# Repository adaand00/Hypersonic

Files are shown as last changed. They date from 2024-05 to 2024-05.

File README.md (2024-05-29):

# Hypersonic
Platform for audio development with ESP32-S3, Work in progress.

Design goals: 
Modularity. Flexibility. High Fidelity. 

Based on previous project: [Supersonic Quantumbox](https://github.com/GustavAbrahamsson/Supersonic-Quantumbox)

## Development progress:

### Hardware
- [x] ESP32-s3 + CODEC module ([`/Hypersonic_pcb`](./Hypersonic_pcb/))
- [x] Pedal with screen, potentiometers, and connetors. ([`/Hypersonic_pedal_pcb`](./Hypersonic_pedal_pcb/))
- [x] Assembled
- [ ] Fully tested

### Software
- [x] Peripheral drivers
- [ ] FreeRTOS system
- [ ] User interface

### Effects

- [x] Saturation (Overdrive/Fuzz)
- [x] VU meter
- [ ] Linear filters
- [ ] Compression
- [ ] Rotary speaker
- [ ] Wah-wah
- [ ] Echo/Reverb

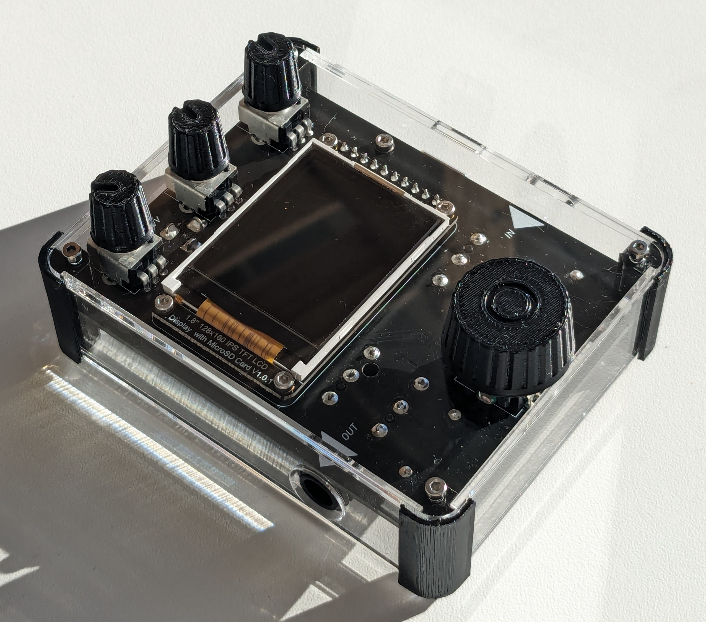
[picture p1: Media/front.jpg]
Pedal


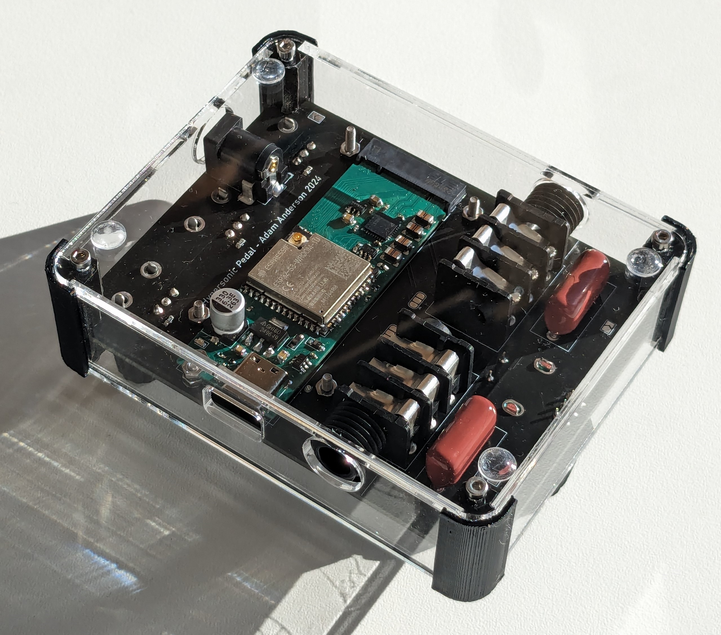
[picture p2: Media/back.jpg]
back


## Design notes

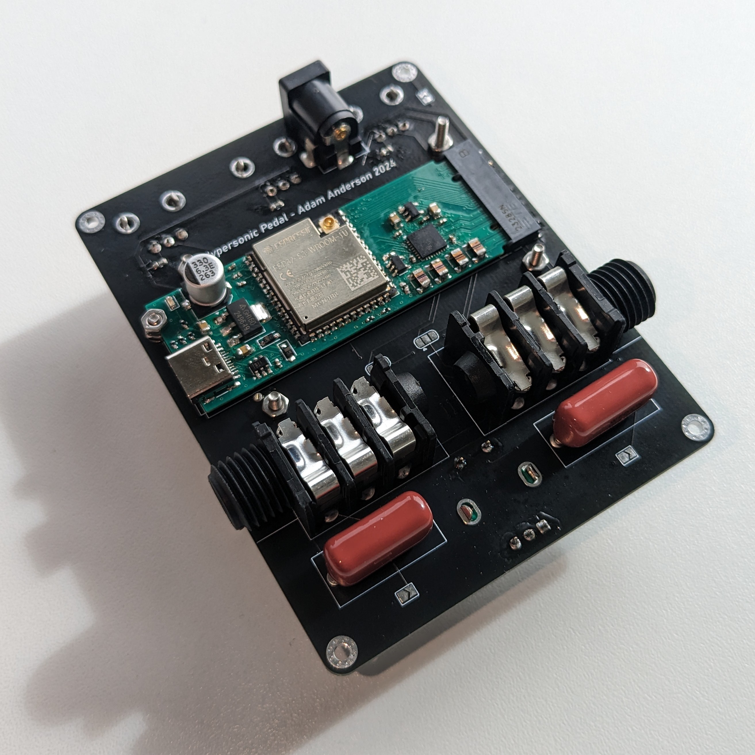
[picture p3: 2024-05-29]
Media/back_open.jpg

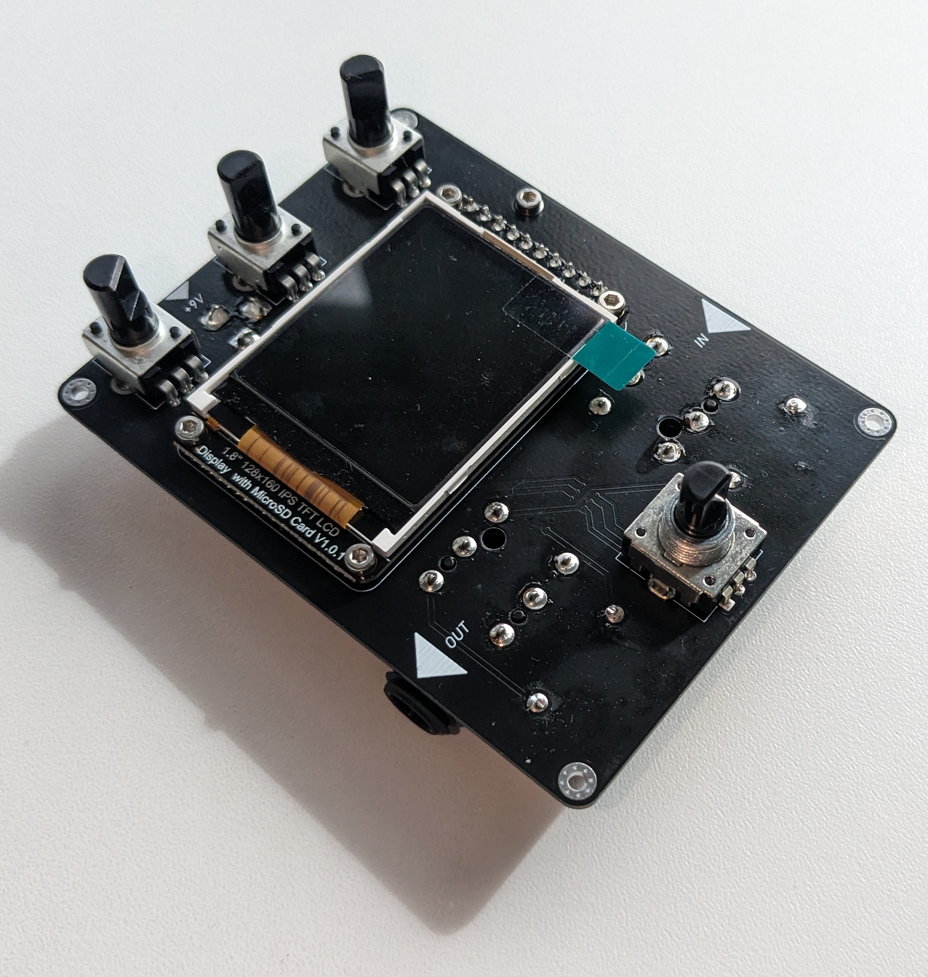
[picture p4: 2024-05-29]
Media/front_open.jpg

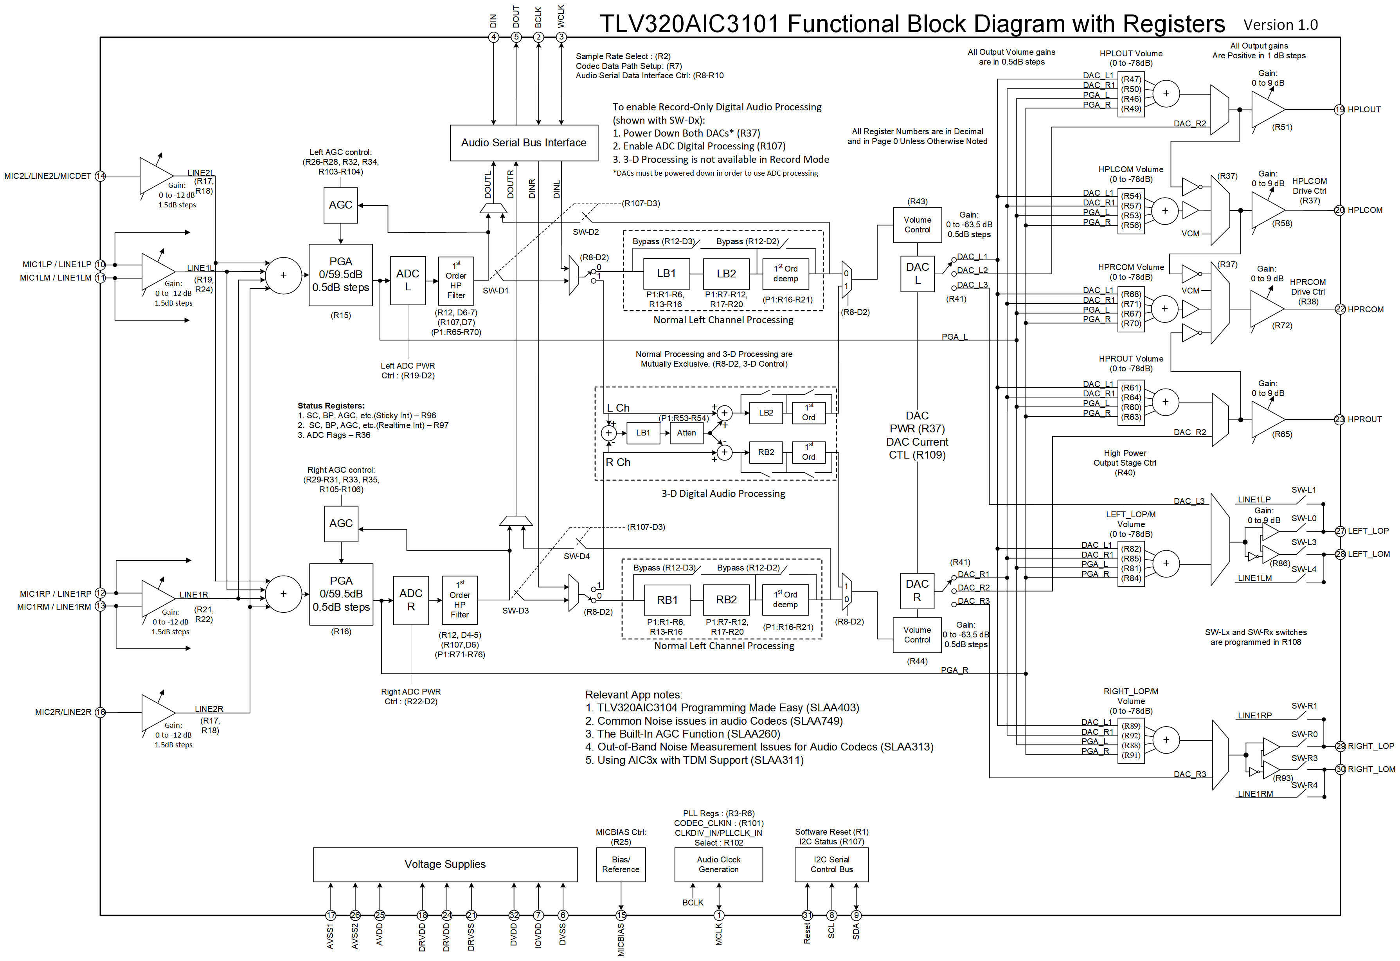
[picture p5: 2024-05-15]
Hypersonic_code/6406.TLV320AIC3101_Functional_block_Diagram_With_Registers.png

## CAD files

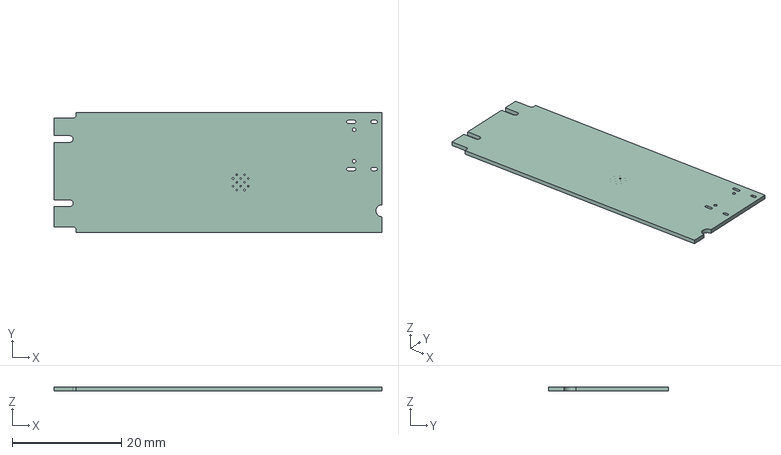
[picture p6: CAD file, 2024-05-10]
Hypersonic_pcb/Hypersonic_pcb.step
60.0 x 22.0 x 0.8 mm

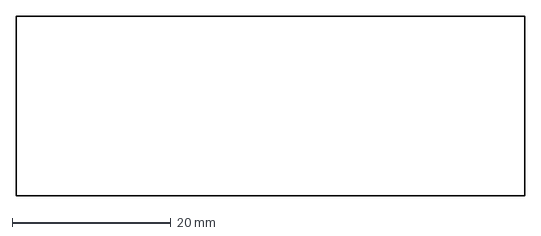
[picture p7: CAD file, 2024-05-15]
Hypersonic_pedal_pcb/case/fron_panel.dxf
64.0 x 22.6 mm

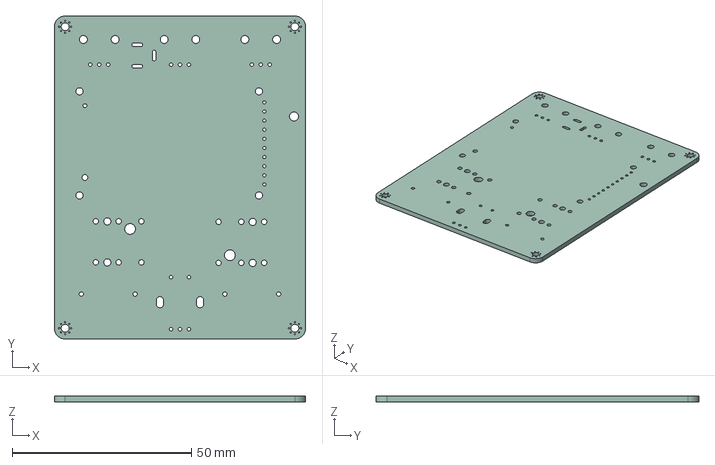
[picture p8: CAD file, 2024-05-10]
Hypersonic_pedal_pcb/Hypersonic_pedal_pcb.step
70.0 x 90.0 x 1.60 mm

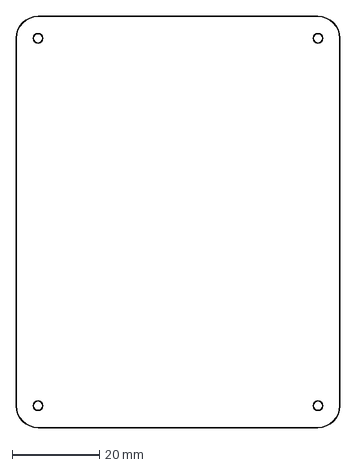
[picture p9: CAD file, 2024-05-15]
Hypersonic_pedal_pcb/case/bottom_panel.dxf
74.0 x 94.0 mm

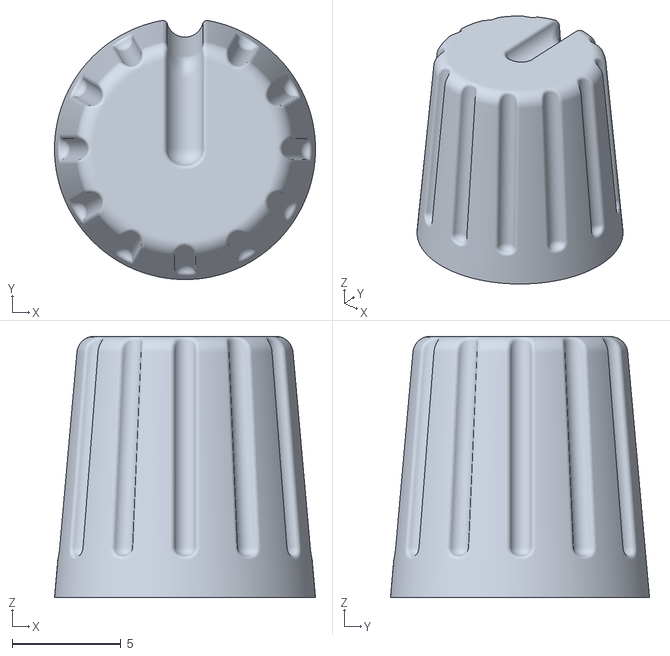
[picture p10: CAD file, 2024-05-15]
Hypersonic_pedal_pcb/case/knob_pot.stl
12.0 x 11.9 x 12.0

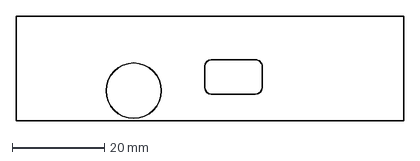
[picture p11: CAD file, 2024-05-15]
Hypersonic_pedal_pcb/case/right_panel.dxf
84.0 x 22.6 mm

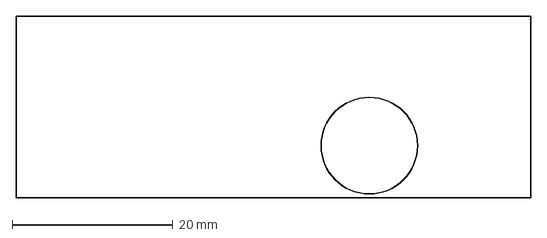
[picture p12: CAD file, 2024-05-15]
Hypersonic_pedal_pcb/case/back_panel.dxf
64.0 x 22.6 mm

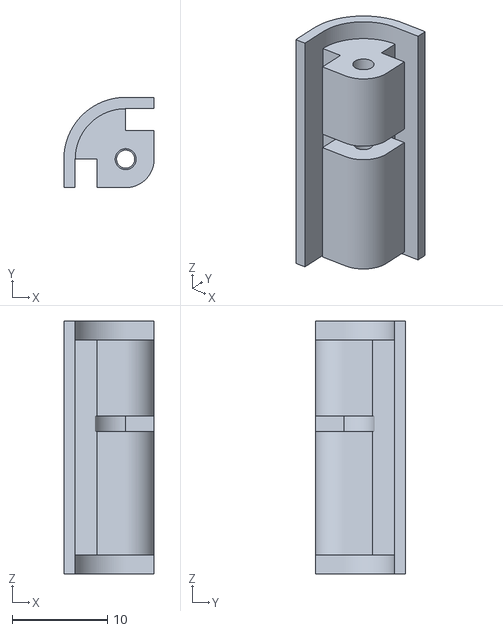
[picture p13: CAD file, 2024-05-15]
Hypersonic_pedal_pcb/case/edge.stl
9.50 x 9.50 x 26.6

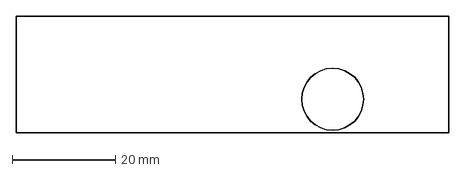
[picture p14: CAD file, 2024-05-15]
Hypersonic_pedal_pcb/case/left_panel.dxf
84.0 x 22.6 mm

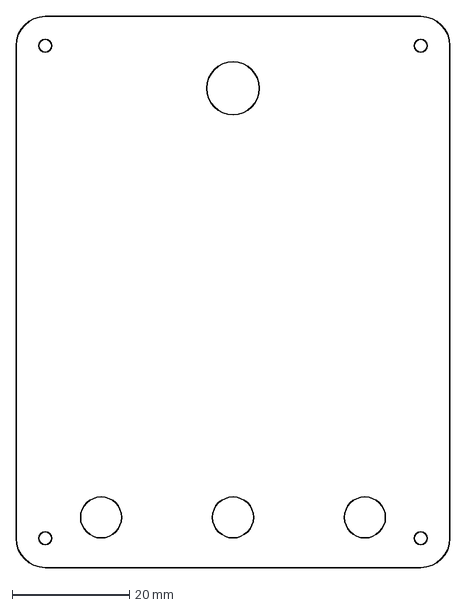
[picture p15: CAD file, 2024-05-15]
Hypersonic_pedal_pcb/case/top_panel.dxf
74.0 x 94.0 mm

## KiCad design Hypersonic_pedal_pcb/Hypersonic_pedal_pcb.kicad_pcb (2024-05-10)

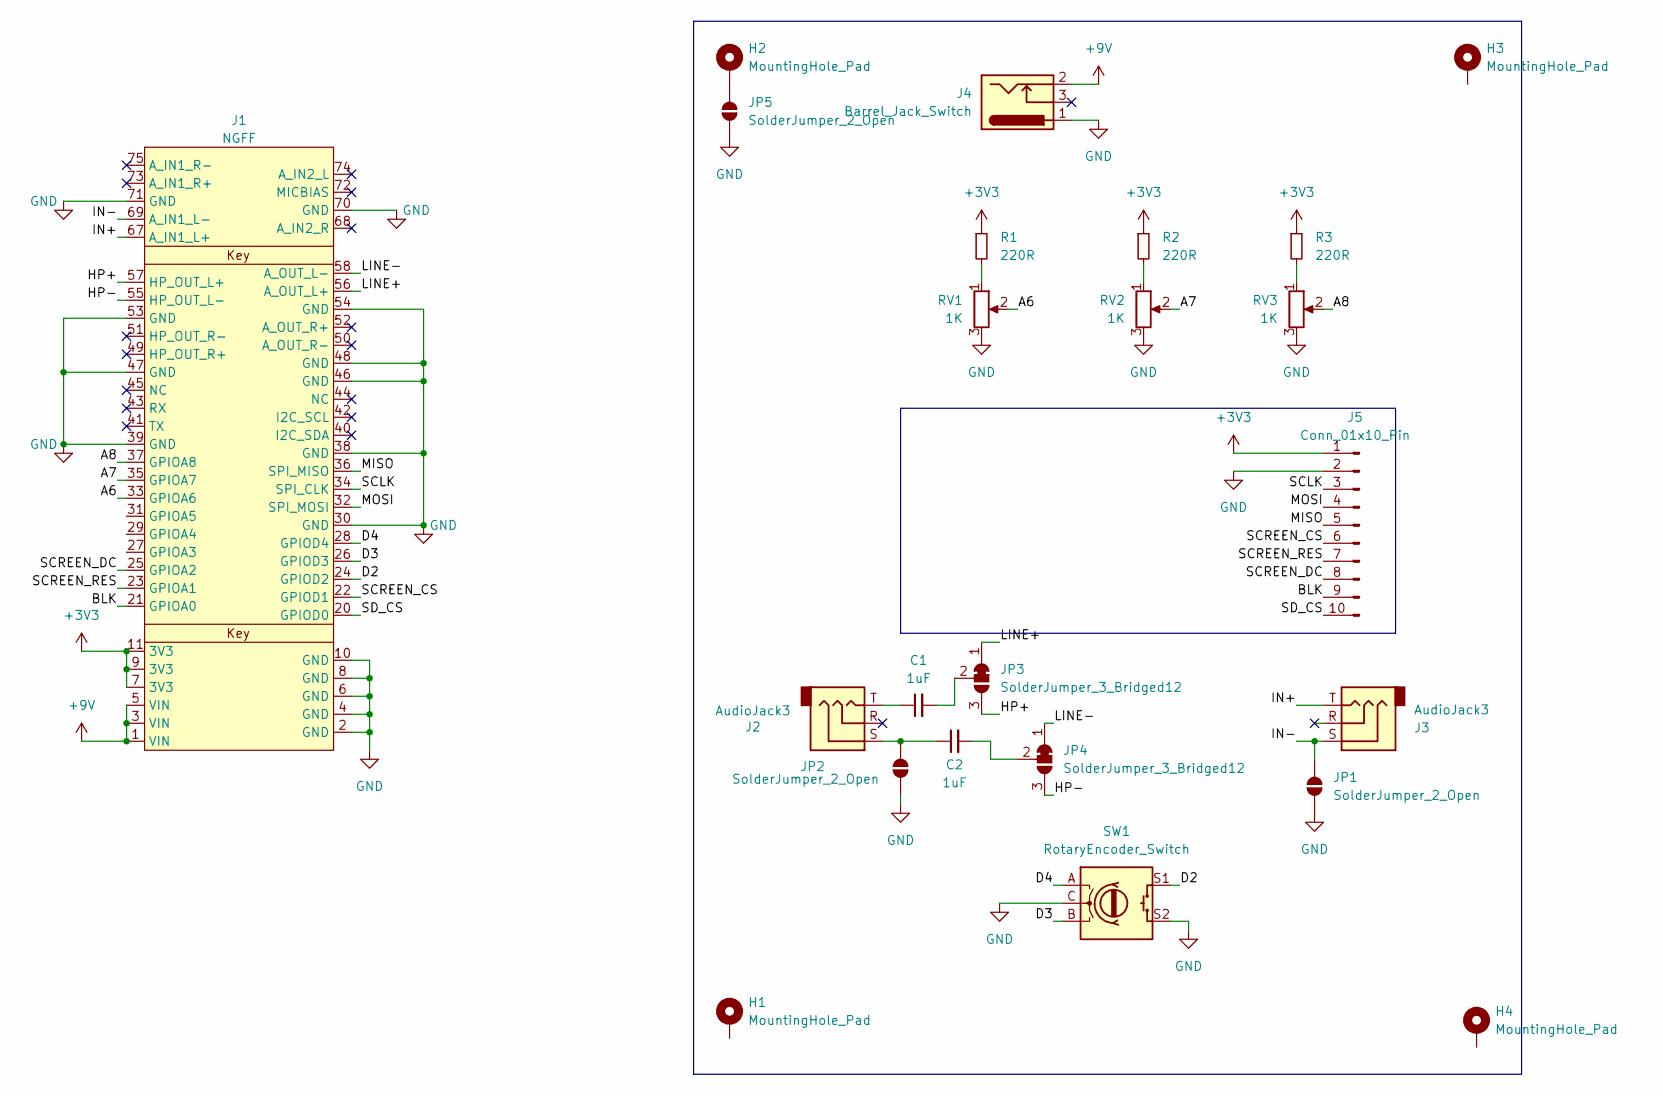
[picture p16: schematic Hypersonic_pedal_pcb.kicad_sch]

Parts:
C1, C2: 1uF; C_Rect_L18.0mm_W8.0mm_P15.00mm_FKS3_FKP3
H1, H2, H3, H4: MountingHole_Pad; MountingHole_2.2mm_M2_Pad_Via
J1: NGFF; TE_2199119-1
J2, J3: AudioJack3; Jack_6.35mm_Neutrik_NRJ6HF_Horizontal
J4: Barrel_Jack_Switch; BarrelJack_Horizontal
J5: Conn_01x10_Pin; DFROBOT_TFT_1_8
JP1, JP2, JP5: SolderJumper_2_Open; SolderJumper-2_P1.3mm_Open_TrianglePad1.0x1.5mm
JP3, JP4: SolderJumper_3_Bridged12; SolderJumper-3_P1.3mm_Bridged12_RoundedPad1.0x1.5mm
R1, R2, R3: 220R; R_0603_1608Metric
RV1, RV2, RV3: 1K; Potentiometer_Bourns_PTV09A-1_Single_Vertical
SW1: RotaryEncoder_Switch; RotaryEncoder_Bourns_Vertical_PEC12R-3x17F-Sxxxx

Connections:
+3V3: J1.7 (3V3), J1.9 (3V3), J1.11 (3V3), J5.1, R1.1, R2.1, R3.1
+9V: J1.1 (VIN), J1.3 (VIN), J1.5 (VIN), J4.2
/A6: J1.33 (GPIOA6), RV1.2
/A7: J1.35 (GPIOA7), RV2.2
/A8: J1.37 (GPIOA8), RV3.2
/BLK: J1.21 (GPIOA0), J5.9
/D2: J1.24 (GPIOD2), SW1.S1
/D3: J1.26 (GPIOD3), SW1.B
/D4: J1.28 (GPIOD4), SW1.A
/HP+: J1.57 (HP_OUT_L+), JP3.3 (B)
/HP-: J1.55 (HP_OUT_L-), JP4.3 (B)
/IN+: J1.67 (A_IN1_L+), J3.T
/IN-: J1.69 (A_IN1_L-), J3.S, JP1.2 (B)
/LINE+: J1.56 (A_OUT_L+), JP3.1 (A)
/LINE-: J1.58 (A_OUT_L-), JP4.1 (A)
/MISO: J1.36 (SPI_MISO), J5.5
/MOSI: J1.32 (SPI_MOSI), J5.4
/SCLK: J1.34 (SPI_CLK), J5.3
/SCREEN_CS: J1.22 (GPIOD1), J5.6
/SCREEN_DC: J1.25 (GPIOA2), J5.8
/SCREEN_RES: J1.23 (GPIOA1), J5.7
/SD_CS: J1.20 (GPIOD0), J5.10
GND: J1.2 (GND), J1.4 (GND), J1.6 (GND), J1.8 (GND), J1.10 (GND), J1.30 (GND), J1.38 (GND), J1.39 (GND), J1.46 (GND), J1.47 (GND), J1.48 (GND), J1.53 (GND), J1.54 (GND), J1.70 (GND), J1.71 (GND), J4.1, J5.2, JP1.1 (A), JP2.1 (A), JP5.1 (A), RV1.3, RV2.3, RV3.3, SW1.C, SW1.S2
unnamed: C1.1, J2.T
unnamed: C2.1, J2.S, JP2.2 (B)
unnamed: C1.2, JP3.2 (C)
unnamed: C2.2, JP4.2 (C)
unnamed: H2.1, JP5.2 (B)
unnamed: R1.2, RV1.1
unnamed: R2.2, RV2.1
unnamed: R3.2, RV3.1

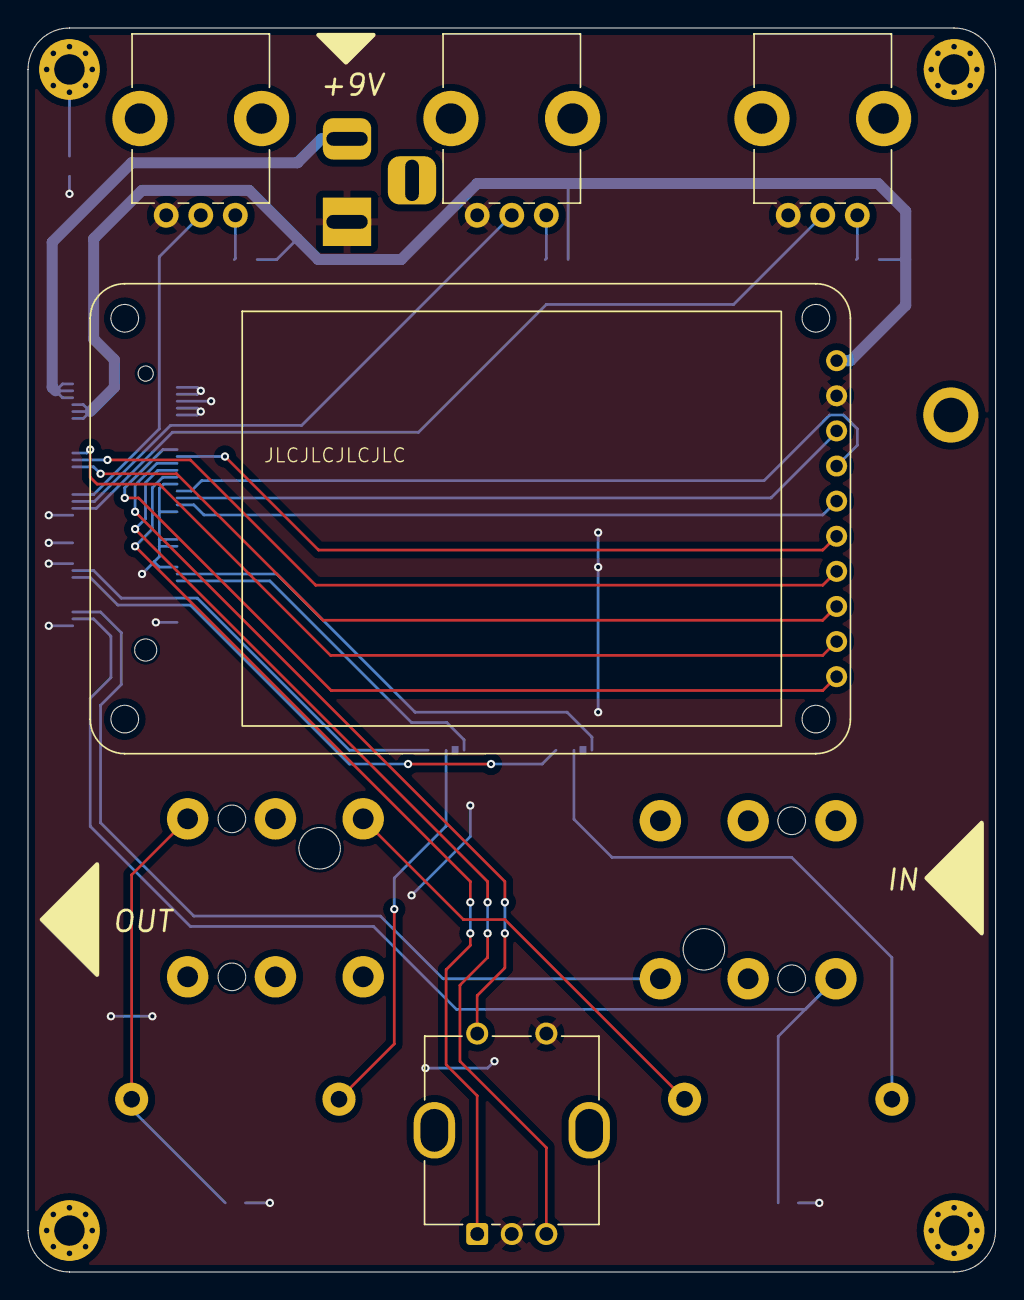
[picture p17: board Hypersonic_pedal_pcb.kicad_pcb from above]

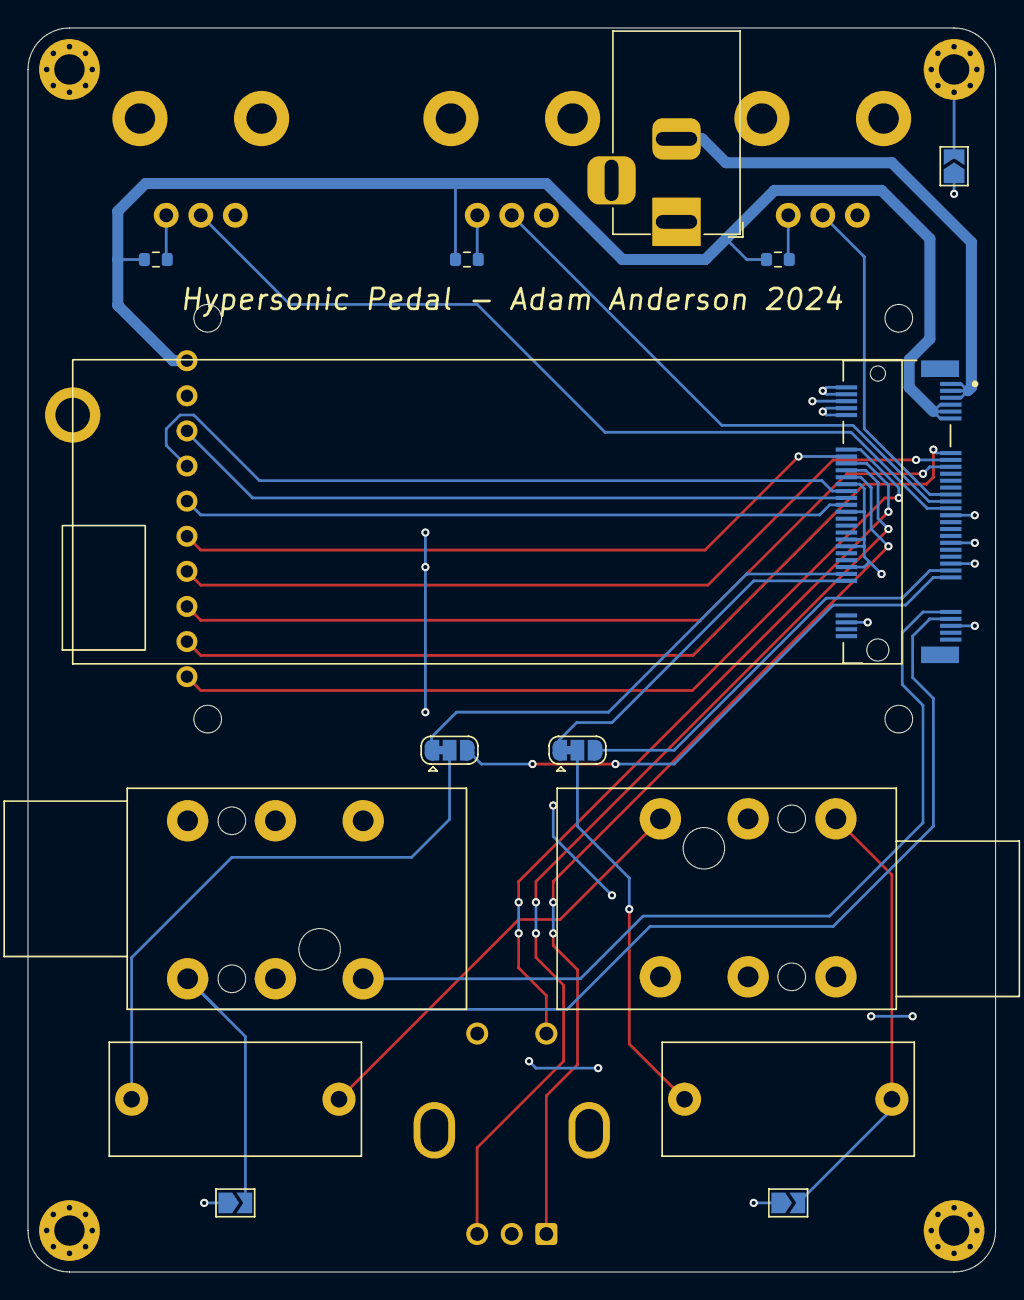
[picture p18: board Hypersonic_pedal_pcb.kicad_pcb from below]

Board: 2 copper layers, 70.0 x 90.0 mm, 23 parts (14 on the bottom side), 31 nets.

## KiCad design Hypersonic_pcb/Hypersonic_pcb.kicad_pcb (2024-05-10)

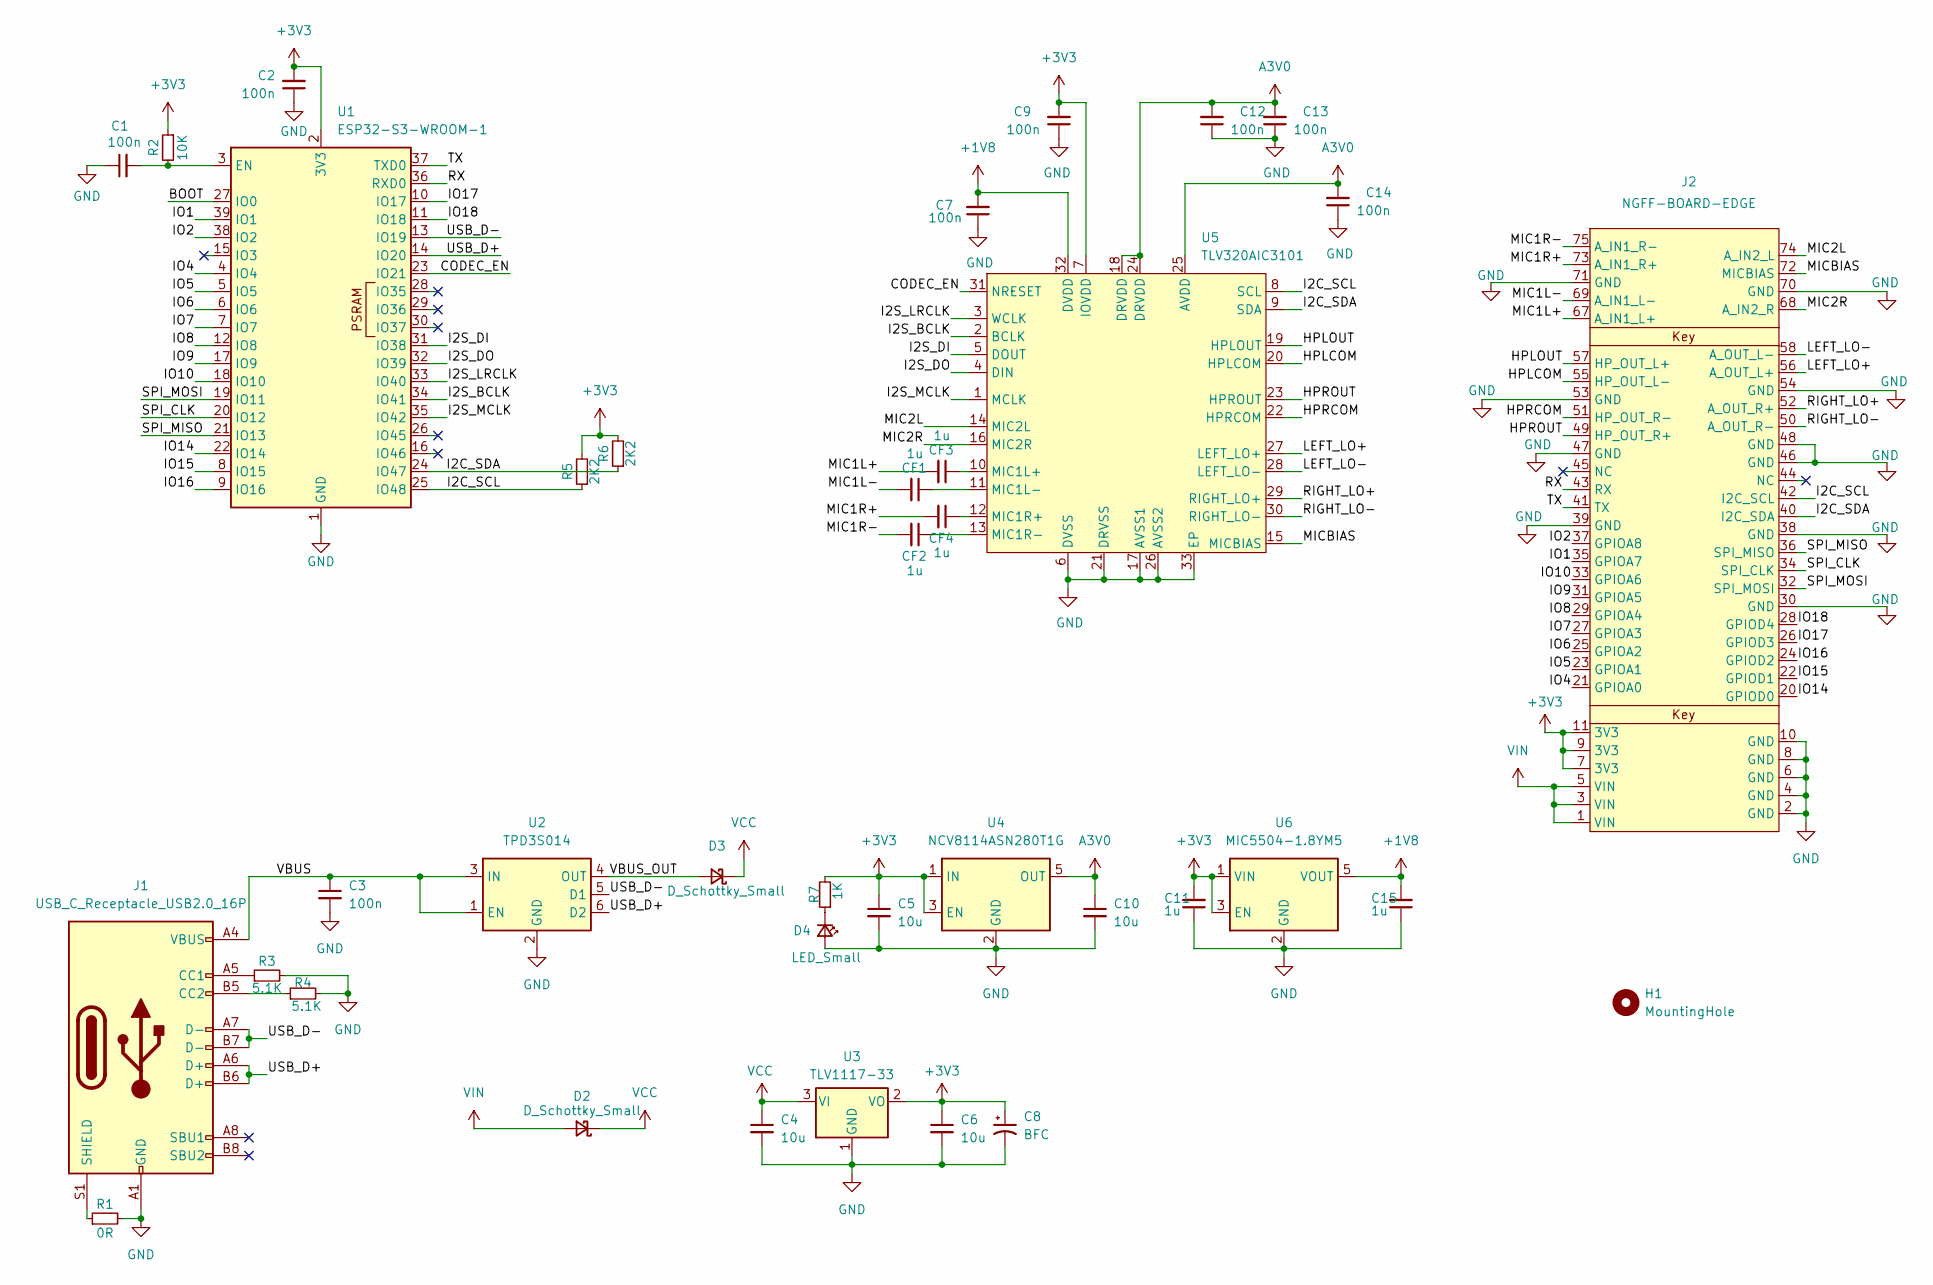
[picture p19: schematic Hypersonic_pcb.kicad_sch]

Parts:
C1, C2, C3, C7, C9, C12, C13, C14: 100n; C_0402_1005Metric
C4, C5, C6, C10: 10u; C_0805_2012Metric
C8: BFC; C_Elec_6.3x5.8
C11, C15: 1u; C_0603_1608Metric
CF1, CF2, CF3, CF4: 1u; C_1210_3225Metric
D2, D3: D_Schottky_Small; D_SOD-323_HandSoldering
D4: LED_Small; LED_0603_1608Metric
H1: MountingHole; MountingHole_2.2mm_M2
J1: USB_C_Receptacle_USB2.0_16P; USB_C_Receptacle_HRO_TYPE-C-31-M-12
J2: NGFF-BOARD-EDGE; NGFF_B+M
R1: 0R; R_0402_1005Metric
R2: 10K; R_0402_1005Metric
R3, R4: 5.1K; R_0402_1005Metric
R5, R6: 2K2; R_0402_1005Metric
R7: 1K; R_0402_1005Metric
U1: ESP32-S3-WROOM-1; ESP32-S3-WROOM-1U
U2: TPD3S014; SOT-23-6
U3: TLV1117-33; SOT-223-3_TabPin2
U4: NCV8114ASN280T1G; TSOT-23-5
U5: TLV320AIC3101; QFN-32-1EP_5x5mm_P0.5mm_EP3.45x3.45mm
U6: MIC5504-1.8YM5; SOT-23-5

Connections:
+1V8: C7.2, C15.2, U5.32 (DVDD), U6.5 (VOUT)
+3V3: C2.2, C5.1, C6.1, C8.1, C9.2, C11.2, J2.7 (3V3), J2.9 (3V3), J2.11 (3V3), R2.1, R5.2, R6.2, R7.2, U1.2 (3V3), U3.2 (VO), U4.1 (IN), U4.3 (EN), U5.7 (IOVDD), U6.1 (VIN), U6.3 (EN)
/BOOT: U1.27 (IO0)
/CODEC_EN: U1.23 (IO21), U5.31 (NRESET)
/HPLCOM: J2.55 (HP_OUT_L-), U5.20 (HPLCOM)
/HPLOUT: J2.57 (HP_OUT_L+), U5.19 (HPLOUT)
/HPRCOM: J2.51 (HP_OUT_R-), U5.22 (HPRCOM)
/HPROUT: J2.49 (HP_OUT_R+), U5.23 (HPROUT)
/I2C_SCL: J2.42 (I2C_SCL), R5.1, U1.25 (IO48), U5.8 (SCL)
/I2C_SDA: J2.40 (I2C_SDA), R6.1, U1.24 (IO47), U5.9 (SDA)
/I2S_BCLK: U1.34 (IO41), U5.2 (BCLK)
/I2S_DI: U1.31 (IO38), U5.5 (DOUT)
/I2S_DO: U1.32 (IO39), U5.4 (DIN)
/I2S_LRCLK: U1.33 (IO40), U5.3 (WCLK)
/I2S_MCLK: U1.35 (IO42), U5.1 (MCLK)
/IO1: J2.35 (GPIOA7), U1.39 (IO1)
/IO2: J2.37 (GPIOA8), U1.38 (IO2)
/IO4: J2.21 (GPIOA0), U1.4 (IO4)
/IO5: J2.23 (GPIOA1), U1.5 (IO5)
/IO6: J2.25 (GPIOA2), U1.6 (IO6)
/IO7: J2.27 (GPIOA3), U1.7 (IO7)
/IO8: J2.29 (GPIOA4), U1.12 (IO8)
/IO9: J2.31 (GPIOA5), U1.17 (IO9)
/IO10: J2.33 (GPIOA6), U1.18 (IO10)
/IO14: J2.20 (GPIOD0), U1.22 (IO14)
/IO15: J2.22 (GPIOD1), U1.8 (IO15)
/IO16: J2.24 (GPIOD2), U1.9 (IO16)
/IO17: J2.26 (GPIOD3), U1.10 (IO17)
/IO18: J2.28 (GPIOD4), U1.11 (IO18)
/LEFT_LO+: J2.56 (A_OUT_L+), U5.27 (LEFT_LO+)
/LEFT_LO-: J2.58 (A_OUT_L-), U5.28 (LEFT_LO-)
/MIC1L+: CF3.2, J2.67 (A_IN1_L+)
/MIC1L-: CF1.2, J2.69 (A_IN1_L-)
/MIC1R+: CF4.2, J2.73 (A_IN1_R+)
/MIC1R-: CF2.2, J2.75 (A_IN1_R-)
/MIC2L: J2.74 (A_IN2_L), U5.14 (MIC2L)
/MIC2R: J2.68 (A_IN2_R), U5.16 (MIC2R)
/MICBIAS: J2.72 (MICBIAS), U5.15 (MICBIAS)
/RIGHT_LO+: J2.52 (A_OUT_R+), U5.29 (RIGHT_LO+)
/RIGHT_LO-: J2.50 (A_OUT_R-), U5.30 (RIGHT_LO-)
/RX: J2.43 (RX), U1.36 (RXD0)
/SPI_CLK: J2.34 (SPI_CLK), U1.20 (IO12)
/SPI_MISO: J2.36 (SPI_MISO), U1.21 (IO13)
/SPI_MOSI: J2.32 (SPI_MOSI), U1.19 (IO11)
/TX: J2.41 (TX), U1.37 (TXD0)
/USB_D+: J1.A6 (D+), J1.B6 (D+), U1.14 (IO20), U2.6 (D2)
/USB_D-: J1.A7 (D-), J1.B7 (D-), U1.13 (IO19), U2.5 (D1)
/VBUS: C3.1, J1.A4 (VBUS), J1.A9 (VBUS), J1.B4 (VBUS), J1.B9 (VBUS), U2.1 (EN), U2.3 (IN)
/VBUS_OUT: D3.2 (A), U2.4 (OUT)
A3V0: C10.1, C12.2, C13.2, C14.2, U4.5 (OUT), U5.18 (DRVDD), U5.24 (DRVDD), U5.25 (AVDD)
GND: C1.1, C2.1, C3.2, C4.2, C5.2, C6.2, C7.1, C8.2, C9.1, C10.2, C11.1, C12.1, C13.1, C14.1, C15.1, D4.2 (A), J1.A1 (GND), J1.A12 (GND), J1.B1 (GND), J1.B12 (GND), J2.2 (GND), J2.4 (GND), J2.6 (GND), J2.8 (GND), J2.10 (GND), J2.30 (GND), J2.38 (GND), J2.39 (GND), J2.46 (GND), J2.47 (GND), J2.48 (GND), J2.53 (GND), J2.54 (GND), J2.70 (GND), J2.71 (GND), R1.2, R3.2, R4.2, U1.1 (GND), U1.40 (GND), U1.41 (GND), U2.2 (GND), U3.1 (GND), U4.2 (GND), U5.6 (DVSS), U5.17 (AVSS1), U5.21 (DRVSS), U5.26 (AVSS2), U5.33 (EP), U6.2 (GND)
unnamed: D4.1 (K), R7.1
unnamed: J1.A5 (CC1), R3.1
unnamed: J1.B5 (CC2), R4.1
unnamed: J1.S1 (SHIELD), R1.1
unnamed: C1.2, R2.2, U1.3 (EN)
unnamed: CF3.1, U5.10 (MIC1L+)
unnamed: CF1.1, U5.11 (MIC1L-)
unnamed: CF4.1, U5.12 (MIC1R+)
unnamed: CF2.1, U5.13 (MIC1R-)
VCC: C4.1, D2.1 (K), D3.1 (K), U3.3 (VI)
VIN: D2.2 (A), J2.1 (VIN), J2.3 (VIN), J2.5 (VIN)

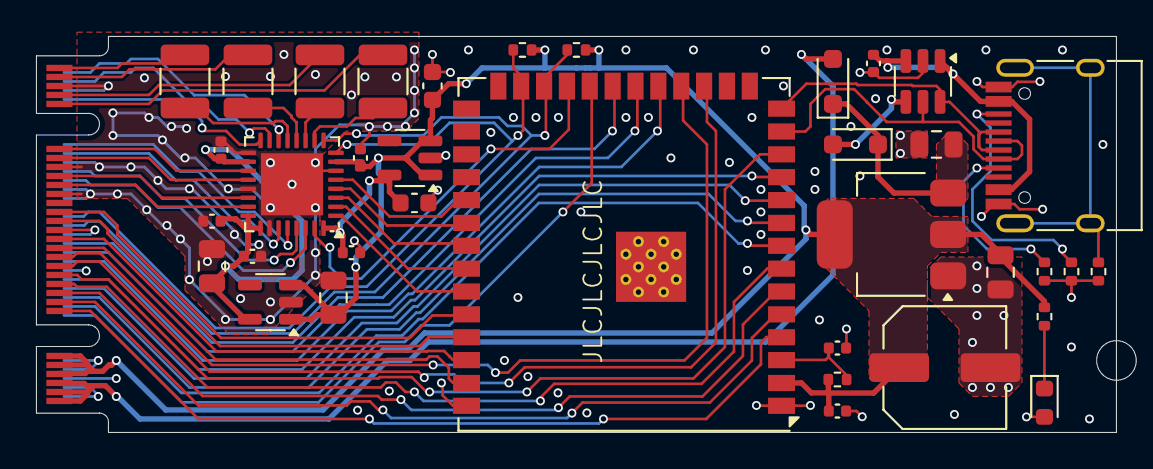
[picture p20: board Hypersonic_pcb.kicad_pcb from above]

Board: 4 copper layers, 60.0 x 22.0 mm, 38 parts (0 on the bottom side), 61 nets.

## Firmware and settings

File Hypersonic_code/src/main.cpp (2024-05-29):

#include <Arduino.h>
#include <vector>
#include <memory>
#include <TFT_eSPI.h>
#include <encoder.h>
#include <tlv320aic3101.h>

#include "gain.h"
#include "Saturatio.h"
#include "meter.h"

#define LCD_BL A0

#define POT0 A6
#define POT1 A7
#define POT2 A8

#define ENC_A D4
#define ENC_B D3
#define ENC_SW D2

std::vector<GenericEffectBuffered *> effects;

TFT_eSPI tft = TFT_eSPI();
int BL_BRIGHTNESS = 100;
TFT_eSprite canvas = TFT_eSprite(&tft);
TFT_eSprite background = TFT_eSprite(&tft);


Encoder enc(ENC_A, ENC_B, ENC_SW);

tlv320aic3101 codec(CODEC_EN, &Wire);

TaskHandle_t dsp_handle;
TaskHandle_t inputs_handle;
TaskHandle_t screen_handle;

int curr_screen = 0;

float pots[3];
constexpr float POT_SCALE = 1.0f/3385.0f;
float pots_alpha = 0.8;

/**
 * @brief reads ADC, does DSP calculations and writes DAC.
*/
void dsp_task(void * params) {

  constexpr int chunksize = 128;

  // Codec init
  float * t1 = (float*) malloc(chunksize*sizeof(float));
  float * t2 = (float*) malloc(chunksize*sizeof(float));

  Wire.setPins(SDA, SCL);

  float T = 0;

  i2s_pin_config_t i2s_pins = {
    .mck_io_num = I2S_MCLK,
    .bck_io_num = I2S_BCLK,
    .ws_io_num = I2S_WCLK,
    .data_out_num = I2S_DO,
    .data_in_num = I2S_DI,
  };

  codec.begin(&i2s_pins);
  delay(1000);

  while (1)
  {
    // Read into t1
    codec.read(t1, chunksize);

    //effects.at(1)->dsp_buffer(t1, t2, chunksize);

    for(int i=0; i<effects.size(); i++){
      // bypass 
      if(effects.at(i)->bypassed){
        continue;
      }
      
      // process effect
      effects.at(i)->dsp_buffer(t1, t2, chunksize);

      // swap pointers
      float * t = t1;
      t1 = t2;
      t2 = t; 
    }

    // Write output buffer
    codec.write(t1, chunksize);

  }
}


/**
 * @brief Reads potentiometer inputs and updates parameters
*/
void inputs_task(void * params) {
  // Timer
  TickType_t lastWake = xTaskGetTickCount();
  const TickType_t period = pdMS_TO_TICKS(10);

  // Pot setup
  pinMode(POT0, INPUT);
  pinMode(POT1, INPUT);
  pinMode(POT2, INPUT);

  while (1)
  {
    pots[0] = pots[0]*pots_alpha + (1-pots_alpha)*analogRead(POT0)*POT_SCALE;
    pots[1] = pots[1]*pots_alpha + (1-pots_alpha)*analogRead(POT1)*POT_SCALE;
    pots[2] = pots[2]*pots_alpha + (1-pots_alpha)*analogRead(POT2)*POT_SCALE;

    

    effects.at(0)->setParam(pots[0], 0);
    effects.at(2)->setParam(pots[1], 1);
    effects.at(2)->setParam(pots[2], 2);
    xTaskDelayUntil(&lastWake, period);
  }
}

/**
 * @brief Handles drawing to the display, as well as keeping track of encoder
*/
void screen_task(void * params) {
  // timer
  TickType_t lastWake = xTaskGetTickCount();
  const TickType_t period = pdMS_TO_TICKS(33);

  // Display setup
  tft.init();
  pinMode(LCD_BL, OUTPUT);
  analogWrite(LCD_BL, BL_BRIGHTNESS);
  tft.setRotation(3);
  tft.fillScreen(TFT_BLACK);
  tft.setCursor(0,0);
  tft.setTextColor(TFT_CYAN, TFT_BLACK);
  tft.setTextSize(1);
  tft.println("Hello World!");

  canvas.setColorDepth(1);
  canvas.createSprite(160,100);

  background.setColorDepth(16);
  background.createSprite(160,100);
  background.fillRectHGradient(0,0,160,100,TFT_PINK, TFT_CYAN);

  while (1)
  {
    canvas.fillSprite(0);
    int c = enc.get_count();
    int es = effects.size();

    tft.setCursor(0,0);

    if (c < 0) {
      enc.set_count(-1);
      curr_screen = -1;
      
      canvas.setCursor(0,0);
      canvas.printf("POT0: %1.3f  \n", pots[0]);
      canvas.printf("POT1: %1.3f  \n", pots[1]);
      canvas.printf("POT2: %1.3f  \n", pots[2]);
      canvas.printf("ENC: %d    \n", enc.get_count());
      canvas.printf("ENC_SW: %d    \n", enc.get_button());
      
    } else {
      if(c >= es) {
        enc.set_count( es-1 );
        c = es-1;
      }

      curr_screen = c;
      
      tft.print(effects.at(curr_screen)->name_.c_str());
      tft.print("        ");

      effects.at(curr_screen)->draw_screen(&canvas);

    }

    canvas.pushSprite(0,28);

    //tft.fillRect(0,28,160,100, TFT_BLACK);
    //tft.pushMaskedImage(0,28,160,100, 
    //  (uint16_t *) background.frameBuffer(0), (uint8_t *) canvas.frameBuffer(0));

    xTaskDelayUntil(&lastWake, period);

  }
}

void setup() {
  // Initialize effects
  effects.push_back(new GainEffect());
  effects.push_back(new Meter());
  effects.push_back(new Saturation());


  // Start tasks  
  xTaskCreatePinnedToCore
    (inputs_task, "inputs", 5000, NULL, 4, &inputs_handle, 0);

  xTaskCreatePinnedToCore
    (screen_task, "screen", 5000, NULL, 2, &screen_handle, 0);

  xTaskCreatePinnedToCore(dsp_task, "DSP", 10000, NULL, 10, &dsp_handle, 1);

}

void loop() {
  delay(10000);
}

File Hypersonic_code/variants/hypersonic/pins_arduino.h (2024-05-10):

#ifndef Pins_Arduino_h
#define Pins_Arduino_h

#include <stdint.h>

#define USB_VID          0x303a
#define USB_PID          0x814D  // for user apps (https://github.com/espressif/usb-pids/pull/77)
#define USB_MANUFACTURER "Adam"
#define USB_PRODUCT      "Hypersonic"
#define USB_SERIAL       ""

// ADC enabled
static const uint8_t A0 = 4;
static const uint8_t A1 = 5;
static const uint8_t A2 = 6;
static const uint8_t A3 = 7;
static const uint8_t A4 = 8;
static const uint8_t A5 = 9;
static const uint8_t A6 = 10;
static const uint8_t A7 = 1;
static const uint8_t A8 = 2;

// No ADC
static const uint8_t D0 = 14;
static const uint8_t D1 = 15;
static const uint8_t D2 = 16;
static const uint8_t D3 = 17;
static const uint8_t D4 = 18;

// SPI
static const uint8_t MISO = 13;
static const uint8_t MOSI = 11;
static const uint8_t SCK  = 12;

static const uint8_t SS   = 10;

// I2C (Pull-ups on board)
static const uint8_t SDA  = 47;
static const uint8_t SCL  = 48;

// Codec pins
static const uint8_t I2S_DI   = 38;
static const uint8_t I2S_DO   = 39;
static const uint8_t I2S_WCLK = 40;
static const uint8_t I2S_BCLK = 41;
static const uint8_t I2S_MCLK = 42;
static const uint8_t CODEC_EN = 21;

// UART
static const uint8_t TX = 43;
static const uint8_t RX = 44;

#endif /* Pins_Arduino_h */

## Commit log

2024-05-05 Add custom pin definitions
2024-05-10 Peripherals working
    [Edge.stl, Hypersonic_pcb.kicad_pcb, Hypersonic_pcb.step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]
2024-05-15 Add effects
    [Edge.stl, back_panel.dxf, bottom_panel.dxf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]
